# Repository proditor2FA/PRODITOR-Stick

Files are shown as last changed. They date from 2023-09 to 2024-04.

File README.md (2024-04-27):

# PRODITOR Solution

https://www.proditor.de

Advanced eight-digit two-factor HOTP solution. Designed to secure remote desktop access.

USB key based on the ATSAM-D11C14 microcontroller. 

This project was build using [Microchip Studio](https://www.microchip.com/en-us/tools-resources/develop/microchip-studio) and [KiCAD](https://www.kicad.org/)

(https://www.proditor.de)

PRODITOR

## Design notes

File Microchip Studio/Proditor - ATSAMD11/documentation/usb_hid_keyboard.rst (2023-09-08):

================
USB HID KEYBOARD
================

OLED1 Xplained pro board must be connected to EXT1 extension header on 
SAMD11/SAMR21/SAMV71/SAME70 boards and to EXT2 on SAMD21/SAMDA1/SAML21/SAML22/
SAMD51/SAME54 boards for the example to work.

This demo behaves like a KEYBOARD based on USB device HID. The Button 1 is used as Ctrl,
Button2 used as Alt, and Button3 used as Del on OLED1 Xplained Board.

Drivers
-------
* USB Device

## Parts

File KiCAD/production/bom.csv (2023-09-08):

Designator | Footprint | Quantity | Value | LCSC Part #
C1, C2 | 0603 | 2 | 1uf
D1 | 0603 | 1 | LED
H1 | MountingHole_3mm | 1 | MountingHole
J1 | USB-PCB | 1 | USB_A_PCB
J2 | PinHeader_1x06_P1.27mm_Vertical_Via0.4mm | 1 | SWD
R1 | 0603 | 1 | 100
SW1 | SW_SPST_EVQQ2 | 1 | SW_Push
U1 | SOIC-14_3.9x8.7mm_P1.27mm | 1 | ATSAMD11C14A-SS
U2 | SOT-23 | 1 | MCP1700x-3V3

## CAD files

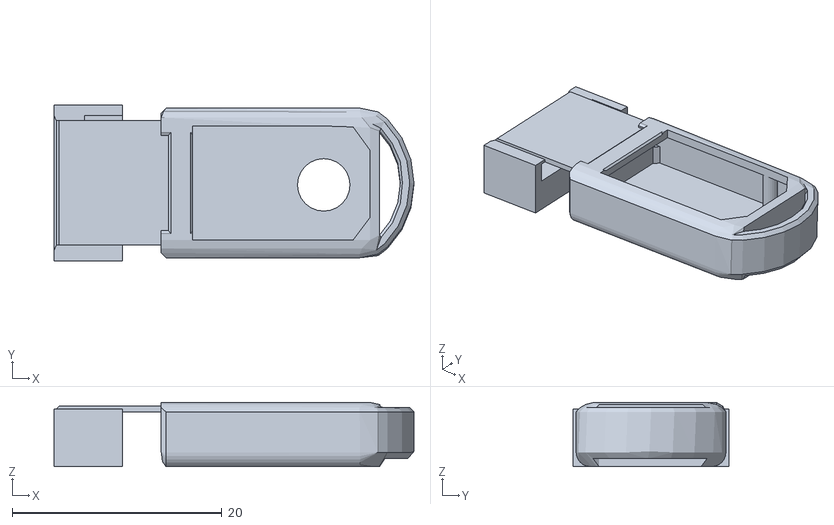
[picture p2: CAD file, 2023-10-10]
STL/Stick.stl
34.3 x 14.9 x 6.11

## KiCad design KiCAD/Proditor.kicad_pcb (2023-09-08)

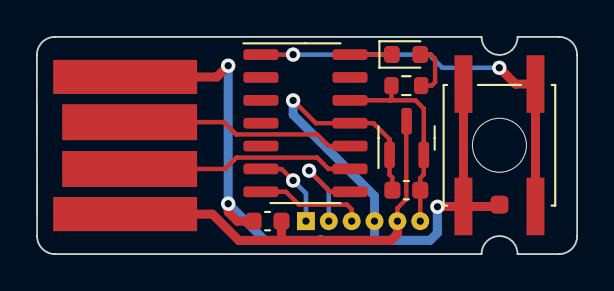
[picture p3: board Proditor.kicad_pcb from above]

Board: 2 copper layers, 30.0 x 12.1 mm, 10 parts (0 on the bottom side), 11 nets.

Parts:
C1, C2: 1uf; C_0603_1608Metric
D1: LED; LED_0603_1608Metric_Mod
H1: MountingHole; MountingHole_3mm
J1: USB_A_PCB; USB-PCB
J2: SWD; PinHeader_1x06_P1.27mm_Vertical_Via0.4mm
R1: 100; R_0603_1608Metric
SW1: SW_Push; SW_SPST_EVQQ2_GND
U1: ATSAMD11C14A-SS; SOIC-14_3.9x8.7mm_P1.27mm
U2: MCP1700x-3V3; SOT-23

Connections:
unnamed: D1.2 (A), R1.1
unnamed: D1.1 (K), U1.14 (PA04)
unnamed: J1.3 (D+), U1.10 (PA25)
unnamed: J1.2 (D-), U1.9 (PA24)
unnamed: C1.2, C2.2, J1.4 (GND), J2.4, SW1.1, U1.11 (GND), U2.1 (GND)
unnamed: C1.1, J1.1 (VBUS), J2.5, U2.3 (VI)
unnamed: J2.1, U1.6 (PA28/~RST)
unnamed: J2.2, U1.8 (PA31/SWDIO)
unnamed: J2.3, U1.7 (PA30/SWCLK)
unnamed: C2.1, J2.6, R1.2, U1.12 (VDD), U2.2 (VO)
unnamed: SW1.2, U1.1 (PA05)

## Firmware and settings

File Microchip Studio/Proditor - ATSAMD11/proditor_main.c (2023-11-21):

/*********************************************************************/
/*   _____   ______  _____  ______  _____ _______  _____   ______    */
/*   |_____] |_____/ |     | |     \   |      |    |     | |_____/   */
/*   |       |    \_ |_____| |_____/ __|__    |    |_____| |    \_   */
/*                                                                   */
/*********************************************************************/

/*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
   You should have received a copy of the GNU General Public License
   along with this program. If not, see <http://www.gnu.org/licenses/>.*/

/*
* 
* Atmel Studio: undefined reference to `_read'
* Project Properties -> Toolchain -> ARM/GNU Linker -> General -> Additional Specs -> Use syscall stubs 
* 
*/

#include "driver_init.h"
#include "hiddf_keyboard.h"
#include "hiddf_keyboard_desc.h"

#include <stdlib.h>
#include <stdio.h>
#include <string.h>
#include <hal_delay.h>
#include "hotp.h"

//read the secret from flash located at position 0x3eec ((last flash page -1) - 0x14)
#define READ_SECRET_FROM_FLASH

//set security bit on first power up for copy protection - only a full chip erase will help! 
//#define SET_SECURITY_BIT_ON_FIRST_STARTUP

//send a roll-key code every 60 seconds for presence detection
#define SEND_ROLL_KEY_EVERY_MINUTE

//hotp setup
static char secret[] = {0x31,0x32,0x33,0x34,0x35,0x36,0x37,0x38,0x39,0x30,0x31,0x32,0x33,0x34,0x35,0x36,0x37,0x38,0x39,0x30}; //12345678901234567890
#define HOTP_DIGITS 8 //6 or 8 digits
//uint32_t expected_6[] = {755224, 287082, 359152, 969429, 338314, 254676, 287922, 162583, 399871, 520489};
//uint32_t expected_8[] = {84755224, 94287082, 37359152, 26969429, 40338314, 68254676, 18287922, 82162583, 73399871, 45520489};

//flash organization
static const uint32_t pageSize[] = { 8, 16, 32, 64, 128, 256, 512, 1024 };
static unsigned char eeBuffer[4];
static uint32_t eePageADDR = 0;

//hotp_main
static char hotpPart[8];
static uint32_t hotpResult = 0;
static uint8_t keyCode = 0;
static bool keyReleased = true;
static uint32_t hCounter = 0;
static uint8_t keyInterval;
static uint16_t softTimer = 3000;
#define rollKeyTiming 60000 //ms
static bool rollKeyReset = false;

static struct hiddf_kb_key_descriptors key_array[3] = {
    {HID_MODIFIER_LEFT_CTRL, true, HID_KB_KEY_UP},
    {HID_MODIFIER_LEFT_ALT, true, HID_KB_KEY_UP},
    {HID_DELETE, false, HID_KB_KEY_UP},
};

static uint8_t ctrl_buffer[64];

static uint8_t single_desc_bytes[] = {
	/* Device descriptors and Configuration descriptors list. */
HID_KEYBOARD_DESCES_LS_FS};

static struct usbd_descriptors single_desc[] = {{single_desc_bytes, single_desc_bytes + sizeof(single_desc_bytes)}
#if CONF_USBD_HS_SP
												,
												{NULL, NULL}
#endif
};


static void usbd_sof_event(void)
{
	/*
	#define HID_1 30
	...
	#define HID_9 38
	#define HID_0 39
	#define HID_ENTER 40
	*/

	if (keyInterval++ > 30) {
		keyInterval = 0;
		if (!keyReleased) {
			gpio_set_pin_level(LED0, 1);
			key_array[2].state = HID_KB_KEY_UP;
			keyReleased = true;
		} else {
			if (keyCode > 0) {
				gpio_set_pin_level(LED0, 0);
				key_array[2].key_id = keyCode;
				key_array[2].state = HID_KB_KEY_DOWN;
				keyCode = 0;
				keyReleased = false;
			}
		}
		hiddf_keyboard_keys_state_change(key_array, 3);
	}
	if(softTimer > 0){
		softTimer --;
	}
}

static struct usbdc_handler usbd_sof_event_h = {NULL, (FUNC_PTR)usbd_sof_event};


void flash_init(void)
{
	eePageADDR = (pageSize[NVMCTRL->PARAM.bit.PSZ] * NVMCTRL->PARAM.bit.NVMP ) - 0x100; //D11 = 0x3F00 - D21 = 0x3FF00
	uint32_t cntValueADDR1 = eePageADDR + 0xc0;
	uint32_t cntValueADDR2 = eePageADDR + 0xf0;

#ifdef READ_SECRET_FROM_FLASH

	uint32_t secretADDR = eePageADDR - 0x14;
	memcpy(secret, (char*)secretADDR, 0x14);

#endif

	memcpy(eeBuffer, (uint32_t *)cntValueADDR1, 0x04); //load counter
	if (eeBuffer[3] == 0xff){
		memcpy(eeBuffer, (uint32_t *)cntValueADDR2, 0x04); //load alt-counter - first start

#ifdef SET_SECURITY_BIT_ON_FIRST_STARTUP

		NVMCTRL->CTRLA.reg = NVMCTRL_CTRLA_CMDEX_KEY | NVMCTRL_CTRLA_CMD_SSB;
		while (!NVMCTRL->INTFLAG.bit.READY);

#endif
	}

	hCounter = (eeBuffer[3] << 24 )| (eeBuffer[2] << 16)| (eeBuffer[1] << 8)| (eeBuffer[0] << 0);
	//hCounter = 0xaabbccdd;
	
	PM->AHBMASK.reg |= PM_AHBMASK_NVMCTRL;
	PM->APBBMASK.reg |= PM_APBBMASK_NVMCTRL;
	//NVMCTRL->CTRLB.bit.MANW = 0;
	// Disable automatic page write
	NVMCTRL->CTRLB.bit.MANW = 1;
}


void flash_write(uint32_t Value)
{
	uint32_t buffer[64]; //256 bytes aligned at 4 byte boundary
	memcpy(buffer, (const void *)eePageADDR, 0x100);
    
	//EE Value store position / last row, two times 
	buffer[48] = Value; buffer[60] = Value;
	
	// Disable Cache
	//uint32_t temp = NVMCTRL->CTRLB.reg;
	//NVMCTRL->CTRLB.reg = temp | NVMCTRL_CTRLB_CACHEDIS;
	
	//Clear error flags
	NVMCTRL->STATUS.reg |= NVMCTRL_STATUS_MASK;
	
	//Set address, command will be issued elsewhere
	NVMCTRL->ADDR.reg = eePageADDR >> 1;
	
	//Erase flash
	NVMCTRL->CTRLA.reg = NVMCTRL_CTRLA_CMDEX_KEY | NVMCTRL_CTRLA_CMD_ER;
	while (0 == NVMCTRL->INTFLAG.bit.READY);

	for (uint32_t i = 0; i < NVMCTRL_ROW_SIZE / sizeof(uint32_t); i++)
	*(uint32_t *)(eePageADDR + i * sizeof(uint32_t)) = buffer[i];
	
	//Execute "WP" Write Page
	NVMCTRL->CTRLA.reg = NVMCTRL_CTRLA_CMDEX_KEY | NVMCTRL_CTRLA_CMD_WP;
	while (!NVMCTRL->INTFLAG.bit.READY);
}


int main(void)
{
	int i = 0;
	system_init();
	
	flash_init();
	
	gpio_set_pin_pull_mode(SW0, GPIO_PULL_UP);

	/* usb stack init */
	usbdc_init(ctrl_buffer);

	/* usbdc_register_funcion inside */
	hiddf_keyboard_init();

	usbdc_start(single_desc);
	usbdc_attach();

	while (!hiddf_keyboard_is_enabled()) {
		// wait hid keyboard to be installed
	};

	usbdc_register_handler(USBDC_HDL_SOF, &usbd_sof_event_h);
	
	gpio_set_pin_level(LED0, 1);
	while (1) {

#ifdef SEND_ROLL_KEY_EVERY_MINUTE

		if ((softTimer == 0) && keyReleased && (keyInterval > 5) ) {
			keyCode = 71; //rollKey (keyCode 145 on Windows)
			softTimer = rollKeyTiming;
			rollKeyReset = true;	
		}
		if (rollKeyReset && keyReleased && (keyInterval > 5) && (keyCode == 0)) {
			keyCode = 71;
			rollKeyReset = false;
		}
		
#endif

		if ((!gpio_get_pin_level(SW0)) && !rollKeyReset && (keyCode == 0)) {
			hCounter ++;
			hotpResult = hotp(HOTP_DIGITS, secret, sizeof(secret), hCounter);
			//sprintf(hotpPart, "%lu", hotpResult);
			int index = HOTP_DIGITS - 1;
			while (hotpResult != 0 && index >= 0) {
				hotpPart[index] = hotpResult % 10;
				hotpResult /= 10;
				index--;
			}

			for (i=0; i<=(HOTP_DIGITS - 1); i++){
				if(hotpPart[i] == 0) {
					keyCode = 39; //zero;
					} else {
					keyCode = (uint8_t)hotpPart[i] + 29;
				}
				while(keyCode > 0) {
				delay_ms(50);
				//gpio_get_pin_level(SW0); //dummy	
				}
			}
	
			keyCode = 40; //0x28 enter
			while ((!gpio_get_pin_level(SW0)) | (keyCode > 0) | (keyReleased == false)) {
			}

		flash_write(hCounter);
		softTimer = rollKeyTiming;
		}
	}
}

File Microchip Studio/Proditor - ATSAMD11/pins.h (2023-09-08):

/*
 * Code generated from Atmel Start.
 *
 * This file will be overwritten when reconfiguring your Atmel Start project.
 * Please copy examples or other code you want to keep to a separate file
 * to avoid losing it when reconfiguring.
 */
#ifndef ATMEL_START_PINS_H_INCLUDED
#define ATMEL_START_PINS_H_INCLUDED

#include <hal_gpio.h>

// SAMD11 has 8 pin functions

#define GPIO_PIN_FUNCTION_A 0
#define GPIO_PIN_FUNCTION_B 1
#define GPIO_PIN_FUNCTION_C 2
#define GPIO_PIN_FUNCTION_D 3
#define GPIO_PIN_FUNCTION_E 4
#define GPIO_PIN_FUNCTION_F 5
#define GPIO_PIN_FUNCTION_G 6
#define GPIO_PIN_FUNCTION_H 7

//#define BUTTON2 GPIO(GPIO_PORTA, 2)
//#define BUTTON3 GPIO(GPIO_PORTA, 3)
//#define BUTTON1 GPIO(GPIO_PORTA, 14)
#define PA24 GPIO(GPIO_PORTA, 24)
#define PA25 GPIO(GPIO_PORTA, 25)

//SAM-D11 xplained
//#define SW0 GPIO(GPIO_PORTA, 14)
//#define LED0 GPIO(GPIO_PORTA, 16)

//PRODITOR Stick
#define SW0 GPIO(GPIO_PORTA, 5)
#define LED0 GPIO(GPIO_PORTA, 4)

#endif // ATMEL_START_PINS_H_INCLUDED

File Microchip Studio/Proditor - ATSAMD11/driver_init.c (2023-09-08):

/*
 * Code generated from Atmel Start.
 *
 * This file will be overwritten when reconfiguring your Atmel Start project.
 * Please copy examples or other code you want to keep to a separate file
 * to avoid losing it when reconfiguring.
 */

#include "driver_init.h"
#include <peripheral_clk_config.h>
#include <utils.h>
#include <hal_init.h>
#include <hpl_gclk_base.h>
#include <hpl_pm_base.h>

void USB_0_PORT_init(void)
{

	gpio_set_pin_direction(PA24,
	                       // <y> Pin direction
	                       // <id> pad_direction
	                       // <GPIO_DIRECTION_OFF"> Off
	                       // <GPIO_DIRECTION_IN"> In
	                       // <GPIO_DIRECTION_OUT"> Out
	                       GPIO_DIRECTION_OUT);

	gpio_set_pin_level(PA24,
	                   // <y> Initial level
	                   // <id> pad_initial_level
	                   // <false"> Low
	                   // <true"> High
	                   false);

	gpio_set_pin_pull_mode(PA24,
	                       // <y> Pull configuration
	                       // <id> pad_pull_config
	                       // <GPIO_PULL_OFF"> Off
	                       // <GPIO_PULL_UP"> Pull-up
	                       // <GPIO_PULL_DOWN"> Pull-down
	                       GPIO_PULL_OFF);

	gpio_set_pin_function(PA24,
	                      // <y> Pin function
	                      // <id> pad_function
	                      // <i> Auto : use driver pinmux if signal is imported by driver, else turn off function
	                      // <PINMUX_PA24G_USB_DM"> Auto
	                      // <GPIO_PIN_FUNCTION_OFF"> Off
	                      // <GPIO_PIN_FUNCTION_A"> A
	                      // <GPIO_PIN_FUNCTION_B"> B
	                      // <GPIO_PIN_FUNCTION_C"> C
	                      // <GPIO_PIN_FUNCTION_D"> D
	                      // <GPIO_PIN_FUNCTION_E"> E
	                      // <GPIO_PIN_FUNCTION_F"> F
	                      // <GPIO_PIN_FUNCTION_G"> G
	                      // <GPIO_PIN_FUNCTION_H"> H
	                      PINMUX_PA24G_USB_DM);

	gpio_set_pin_direction(PA25,
	                       // <y> Pin direction
	                       // <id> pad_direction
	                       // <GPIO_DIRECTION_OFF"> Off
	                       // <GPIO_DIRECTION_IN"> In
	                       // <GPIO_DIRECTION_OUT"> Out
	                       GPIO_DIRECTION_OUT);

	gpio_set_pin_level(PA25,
	                   // <y> Initial level
	                   // <id> pad_initial_level
	                   // <false"> Low
	                   // <true"> High
	                   false);

	gpio_set_pin_pull_mode(PA25,
	                       // <y> Pull configuration
	                       // <id> pad_pull_config
	                       // <GPIO_PULL_OFF"> Off
	                       // <GPIO_PULL_UP"> Pull-up
	                       // <GPIO_PULL_DOWN"> Pull-down
	                       GPIO_PULL_OFF);

	gpio_set_pin_function(PA25,
	                      // <y> Pin function
	                      // <id> pad_function
	                      // <i> Auto : use driver pinmux if signal is imported by driver, else turn off function
	                      // <PINMUX_PA25G_USB_DP"> Auto
	                      // <GPIO_PIN_FUNCTION_OFF"> Off
	                      // <GPIO_PIN_FUNCTION_A"> A
	                      // <GPIO_PIN_FUNCTION_B"> B
	                      // <GPIO_PIN_FUNCTION_C"> C
	                      // <GPIO_PIN_FUNCTION_D"> D
	                      // <GPIO_PIN_FUNCTION_E"> E
	                      // <GPIO_PIN_FUNCTION_F"> F
	                      // <GPIO_PIN_FUNCTION_G"> G
	                      // <GPIO_PIN_FUNCTION_H"> H
	                      PINMUX_PA25G_USB_DP);
}

/* The USB module requires a GCLK_USB of 48 MHz ~ 0.25% clock
 * for low speed and full speed operation. */
#if (CONF_GCLK_USB_FREQUENCY > (48000000 + 48000000 / 400)) || (CONF_GCLK_USB_FREQUENCY < (48000000 - 48000000 / 400))
#warning USB clock should be 48MHz ~ 0.25% clock, check your configuration!
#endif

void USB_0_CLOCK_init(void)
{

	_pm_enable_bus_clock(PM_BUS_APBB, USB);
	_pm_enable_bus_clock(PM_BUS_AHB, USB);
	_gclk_enable_channel(USB_GCLK_ID, CONF_GCLK_USB_SRC);
}

void USB_0_init(void)
{
	USB_0_CLOCK_init();
	usb_d_init();
	USB_0_PORT_init();
}

void system_init(void)
{
	init_mcu();

// GPIO on PA14

// Set pin direction to input
gpio_set_pin_direction(SW0, GPIO_DIRECTION_IN);

gpio_set_pin_pull_mode(SW0,
// <y> Pull configuration
// <id> pad_pull_config
// <GPIO_PULL_OFF"> Off
// <GPIO_PULL_UP"> Pull-up
// <GPIO_PULL_DOWN"> Pull-down
GPIO_PULL_UP);

gpio_set_pin_function(SW0, GPIO_PIN_FUNCTION_OFF);

// GPIO on PA16

gpio_set_pin_level(LED0,
// <y> Initial level
// <id> pad_initial_level
// <false"> Low
// <true"> High
false);

// Set pin direction to output
gpio_set_pin_direction(LED0, GPIO_DIRECTION_OUT);

gpio_set_pin_function(LED0, GPIO_PIN_FUNCTION_OFF);



	USB_0_init();
}

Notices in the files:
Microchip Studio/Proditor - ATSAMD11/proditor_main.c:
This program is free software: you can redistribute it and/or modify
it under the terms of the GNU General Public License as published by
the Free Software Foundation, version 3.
